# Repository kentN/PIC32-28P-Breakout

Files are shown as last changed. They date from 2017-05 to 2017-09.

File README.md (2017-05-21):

# PIC32-28P-Breakout
Breakout board for PIC32 SSOP28 packages

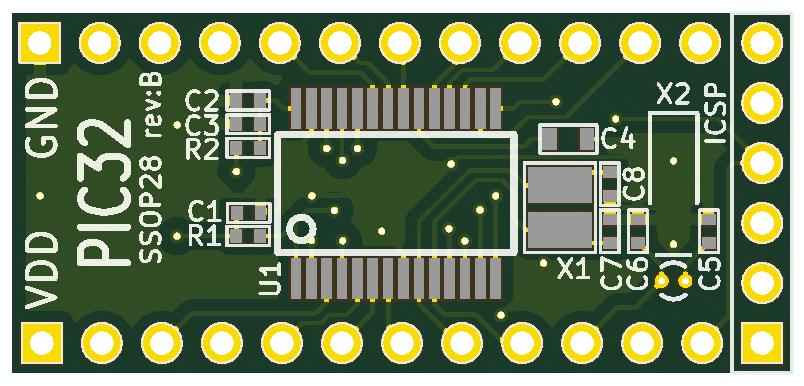
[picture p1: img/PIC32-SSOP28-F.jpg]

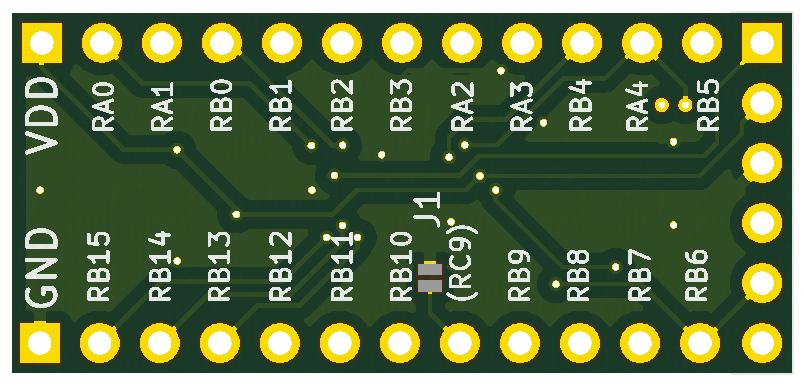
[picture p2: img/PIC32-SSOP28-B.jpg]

## Features ##
- Two External Clock Option (EXTAL, SOSC)
- ICSP port (PGx3) for PIC32MM, PIC32MX1XX Series
- PIN19: user selectable, RC9(PIC32MM) or VSS (Soldering Jumper for PIC32MX) 
- Size: 33x15.2mm

## Support MCUs ##
- ◎ PIC32MMXXXXGPL028
- 〇 PIC32MX1XX
- △ PIC32MX2XX (ICSP PGC,PGD not work)

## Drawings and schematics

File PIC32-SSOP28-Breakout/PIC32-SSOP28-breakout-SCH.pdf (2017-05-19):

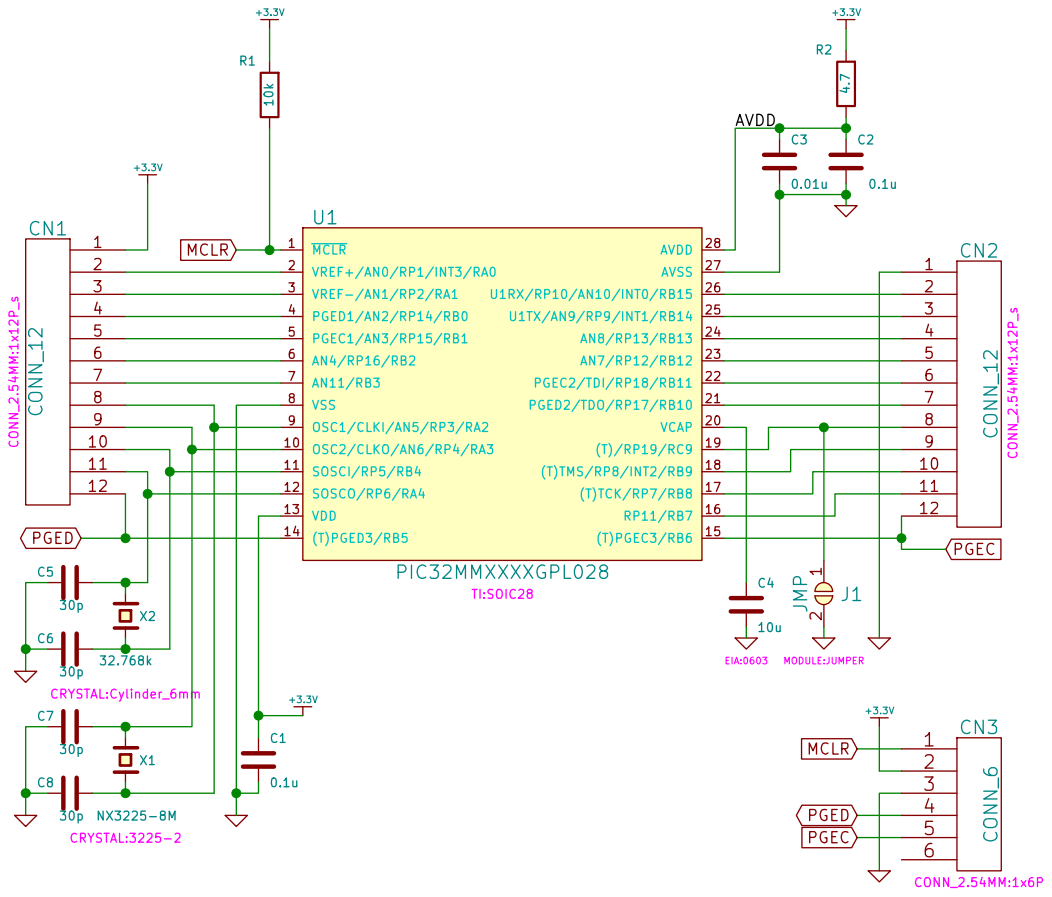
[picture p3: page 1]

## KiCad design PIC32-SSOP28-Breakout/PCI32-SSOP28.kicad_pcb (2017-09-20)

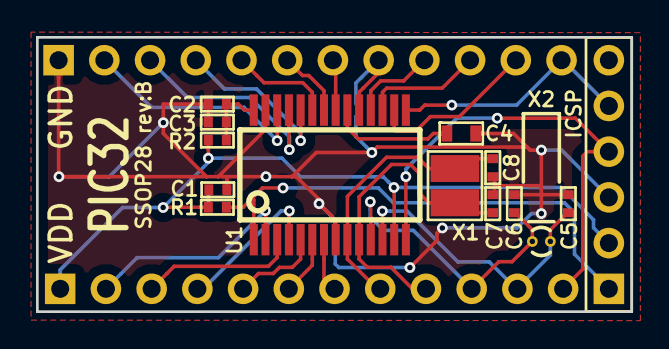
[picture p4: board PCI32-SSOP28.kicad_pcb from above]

Board: 2 copper layers, 33.0 x 15.2 mm, 17 parts (1 on the bottom side), 27 nets.

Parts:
C1, C2: 0.1u; 0402
C3: 0.01u; 0402
C4: 10u; 0603
C5, C6, C7, C8: 30p; 0402
CN1, CN2: CONN_12; 1x12P_s
ICSP: CONN_6; 1x6P
J1: JMP; JUMPER
R1: 10k; 0402
R2: 4.7; 0402
U1: PIC32MMXXXXGPL028; SOIC28
X1: NX3225-8M; 3225-2
X2: 32.768k; Cylinder_6mm

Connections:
+3.3V: C1.1, CN1.1, ICSP.2, R1.2, R2.2, U1.13
/AVDD: C2.1, C3.1, R2.1, U1.28
GND: C1.2, C2.2, C3.2, C4.2, C5.2, C6.2, C7.2, C8.2, CN2.1, ICSP.3, J1.2, U1.8, U1.27
MCLR: ICSP.1, R1.1, U1.1
unnamed: C4.1, U1.20
unnamed: C5.1, CN1.11, U1.12, X2.1
unnamed: C6.1, CN1.10, U1.11, X2.2
unnamed: C7.1, CN1.9, U1.10, X1.1
unnamed: C8.1, CN1.8, U1.9, X1.2
unnamed: CN1.2, U1.2
unnamed: CN1.3, U1.3
unnamed: CN1.4, U1.4
unnamed: CN1.5, U1.5
unnamed: CN1.6, U1.6
unnamed: CN1.7, U1.7
unnamed: CN2.2, U1.26
unnamed: CN2.3, U1.25
unnamed: CN2.4, U1.24
unnamed: CN2.5, U1.23
unnamed: CN2.6, U1.22
unnamed: CN2.7, U1.21
unnamed: CN2.8, J1.1, U1.19
unnamed: CN2.9, U1.18
unnamed: CN2.10, U1.17
unnamed: CN2.11, U1.16
PGEC: CN2.12, ICSP.5, U1.15
PGED: CN1.12, ICSP.4, U1.14
